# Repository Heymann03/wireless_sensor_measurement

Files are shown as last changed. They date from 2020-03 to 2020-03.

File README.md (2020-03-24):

# master research project
## Design and Realization of Wireless Measurement System for Resistive Sensors
### Objectives
1. Measuring the resistance of a sensor of any given range from 200K - 6M.
2. Displaying the data through an OLED.
3. Transmitting the acquired data to a remote station.
4. Monitoring the resistance in real-time.
5. Recording the measured data.

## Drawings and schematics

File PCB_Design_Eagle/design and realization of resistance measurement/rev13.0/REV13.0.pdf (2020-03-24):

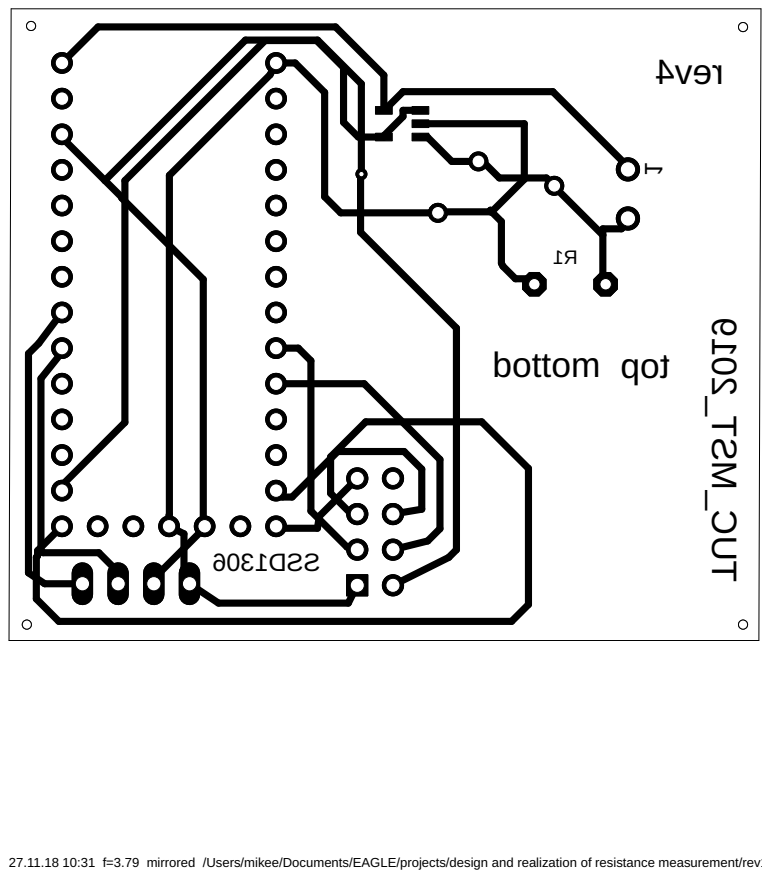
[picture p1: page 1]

27.11.18 10:31 f=3.79 mirrored /Users/mikee/Documents/EAGLE/projects/design and realization of resistance measurement/rev13.0/REV13.0.brd

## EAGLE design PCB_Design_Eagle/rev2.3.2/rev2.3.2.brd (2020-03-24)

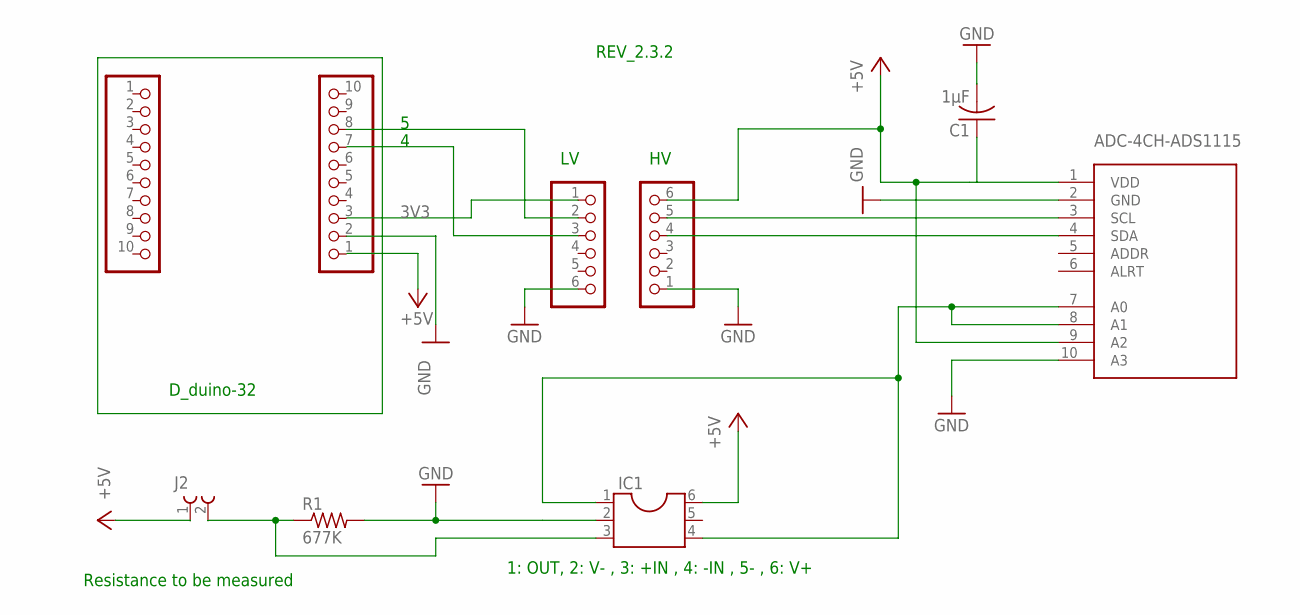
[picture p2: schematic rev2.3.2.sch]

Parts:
C1: 1µF; C025-025X050
IC1: DIL6S; SOCKET-06
J2: 691103110002
JP1, JP4: PINHD-1X6; 1X06
JP3, JP5: PINHD-1X10; 1X10
R1: 677K; 0204/5
U$1: ADC-4CH-ADS1115

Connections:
3V3: JP1.1
4: JP1.3
+5V: IC1.6, J2.1
A1: IC1.1, IC1.4, U$1.7 (A0), U$1.8 (A1)
GND: C1.2, IC1.2, JP1.6, JP4.1, JP5.2, R1.2, U$1.2 (GND), U$1.10 (A3)
unnamed: IC1.3, J2.2, R1.1
unnamed: JP1.2, JP5.8
unnamed: JP4.5, U$1.3 (SCL)
unnamed: JP4.4, U$1.4 (SDA)
VDD: C1.1, JP4.6, U$1.9 (A2)

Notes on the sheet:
Resistance to be measured
1: OUT, 2: V- , 3: +IN , 4: -IN , 5- , 6: V+
D_duino-32
REV_2.3.2

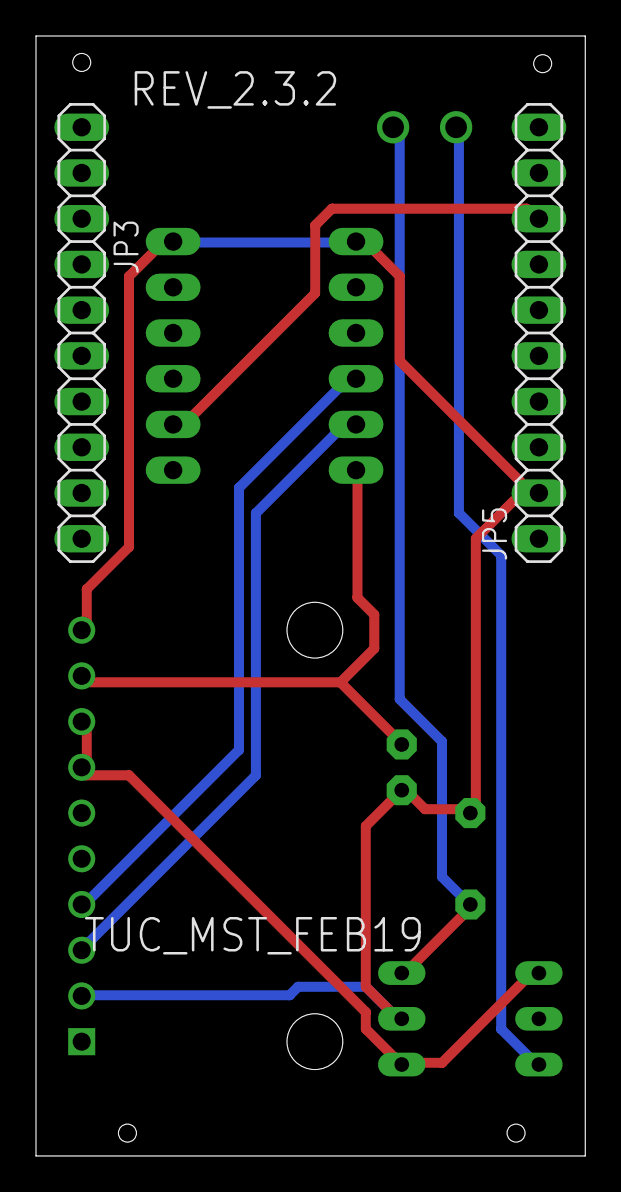
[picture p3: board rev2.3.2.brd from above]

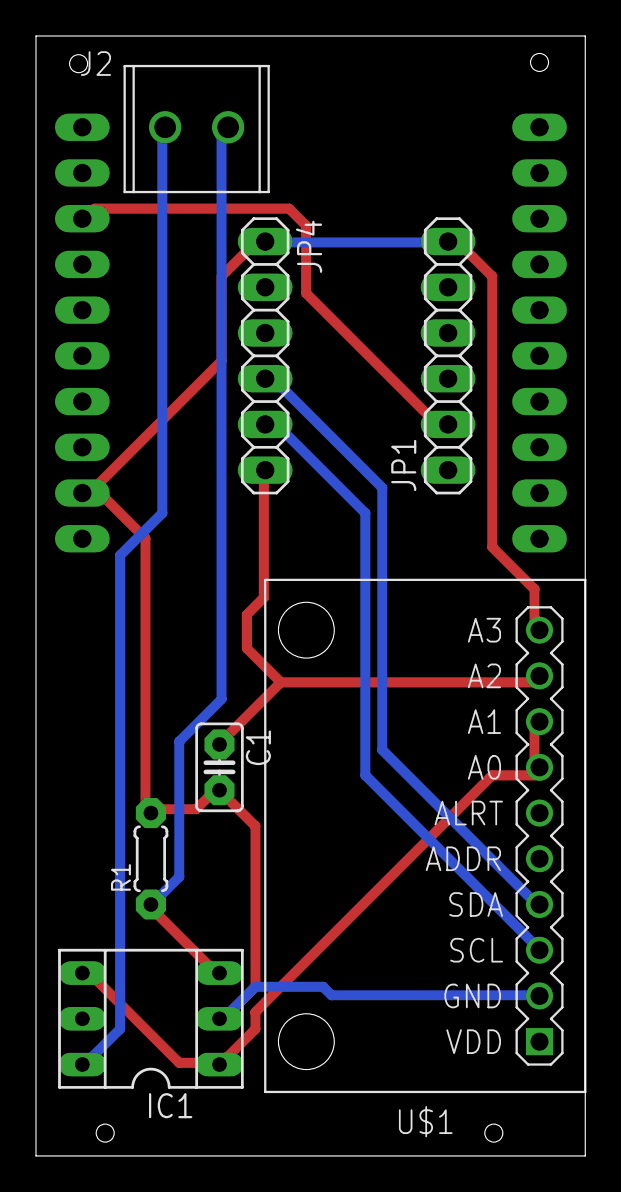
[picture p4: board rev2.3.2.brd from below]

Board: 2 copper layers, 30.5 x 62.2 mm, 9 parts (7 on the bottom side), 8 nets.

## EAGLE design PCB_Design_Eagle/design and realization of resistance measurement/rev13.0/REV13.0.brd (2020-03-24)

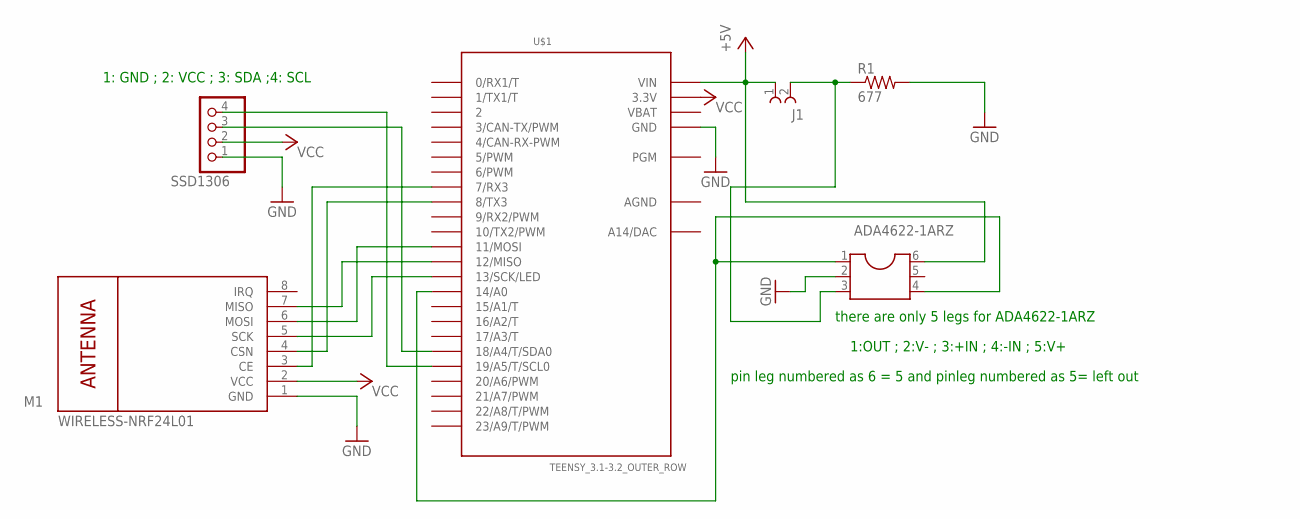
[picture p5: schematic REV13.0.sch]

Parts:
ADA4622-1ARZ: DIL6/4; DIL06-4
J1: 691214100002
M1: WIRELESS-NRF24L01
R1: 677; 0204/5
SSD1306: PINHD-1X4; 1X04
U$1: TEENSY_3.1-3.2_OUTER_ROW; TEENSY_3.0-3.2&LC_OUTER_ROW

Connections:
+5V: ADA4622-1ARZ.6, J1.1 (2), U$1.VIN
AGND: U$1.AGND
GND: ADA4622-1ARZ.2, M1.1 (GND), R1.2, SSD1306.1, U$1.GND, U$1.GND1 (GND)
unnamed: ADA4622-1ARZ.3, J1.2 (1), R1.1
unnamed: M1.5 (SCK), U$1.13 (13/SCK/LED)
unnamed: M1.6 (MOSI), U$1.11 (11/MOSI)
unnamed: M1.7 (MISO), U$1.12 (12/MISO)
unnamed: M1.4 (CSN), U$1.8 (8/TX3)
unnamed: M1.3 (CE), U$1.7 (7/RX3)
unnamed: SSD1306.4, U$1.19/A5 (19/A5/T/SCL0)
unnamed: SSD1306.3, U$1.18/A4 (18/A4/T/SDA0)
unnamed: ADA4622-1ARZ.1, ADA4622-1ARZ.4, U$1.14/A0
VBAT: U$1.VBAT
VCC: M1.2 (VCC), SSD1306.2, U$1.3.3V, U$1.3.3V1 (3.3V)

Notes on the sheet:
1: GND ; 2: VCC ; 3: SDA ;4: SCL
1:OUT ; 2:V- ; 3:+IN ; 4:-IN ; 5:V+
pin leg numbered as 6 = 5 and pinleg numbered as 5= left out
there are only 5 legs for ADA4622-1ARZ

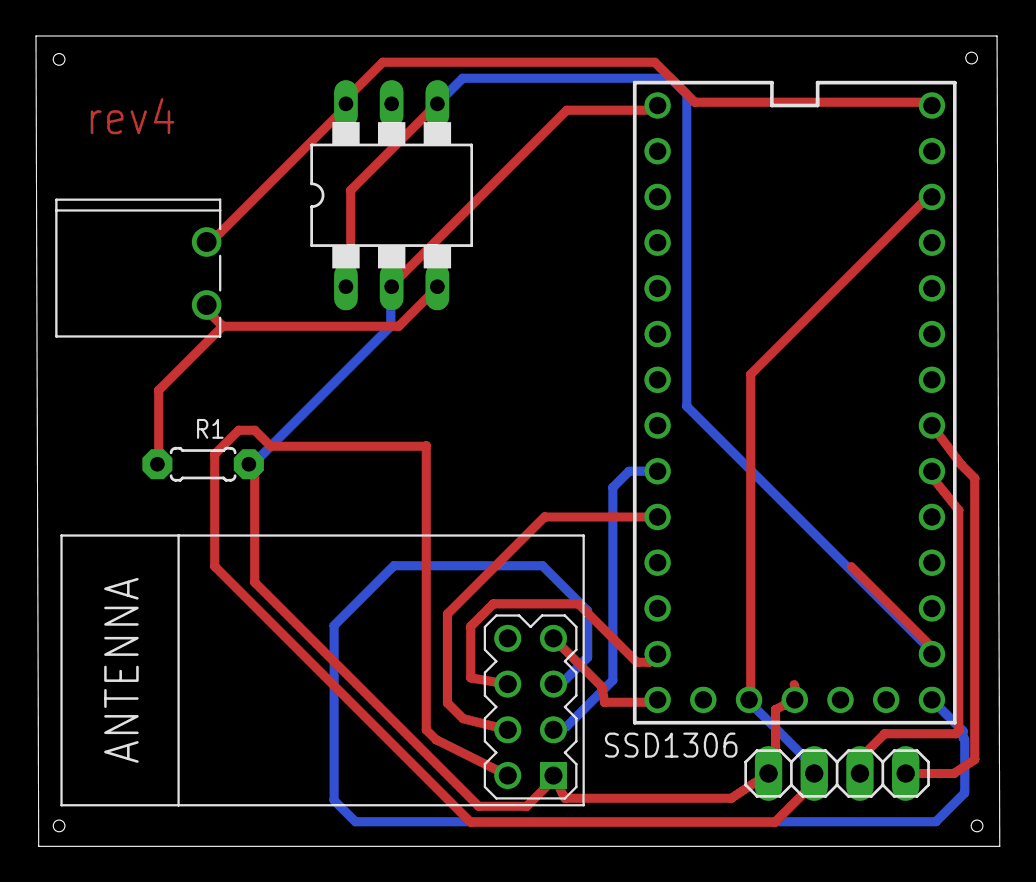
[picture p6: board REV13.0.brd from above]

Board: 2 copper layers, 53.5 x 45.0 mm, 6 parts (0 on the bottom side), 12 nets.

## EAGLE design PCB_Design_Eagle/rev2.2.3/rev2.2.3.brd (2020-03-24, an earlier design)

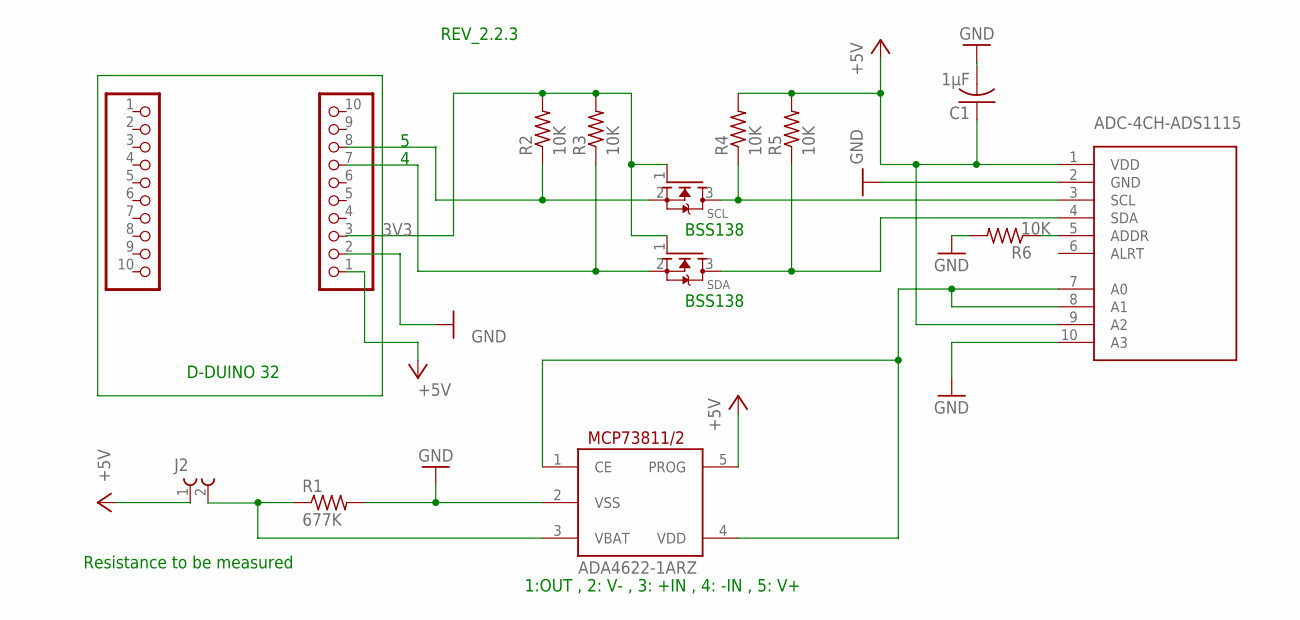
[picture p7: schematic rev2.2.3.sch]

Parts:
ADA4622-1ARZ: MCP73811/2; SOT23-5L
C1: 1µF; C1608
J2: 691103110002
JP1, JP3: PINHD-1X10; 1X10
R1: 677K; M0805
R2, R3, R4, R5, R6: 10K; M0805
SCL: MOSFET-NWAVE; SOT23-W
SDA: MOSFET-NWAVE; SOT23-W
U$1: ADC-4CH-ADS1115

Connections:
3V3: JP1.3, R2.2, R3.2, SCL.1 (G), SDA.1 (G)
4: JP1.7, R3.1, SDA.2 (S)
+5V: ADA4622-1ARZ.5 (PROG), J2.1, JP1.1
A1: ADA4622-1ARZ.1 (CE), ADA4622-1ARZ.4 (VDD), U$1.7 (A0), U$1.8 (A1)
GND: ADA4622-1ARZ.2 (VSS), C1.2, JP1.2, R1.2, R6.2, U$1.2 (GND), U$1.10 (A3)
unnamed: ADA4622-1ARZ.3 (VBAT), J2.2, R1.1
unnamed: JP1.8, R2.1, SCL.2 (S)
unnamed: R6.1, U$1.5 (ADDR)
SCL: R4.1, SCL.3 (D), U$1.3 (SCL)
SDA: R5.1, SDA.3 (D), U$1.4 (SDA)
VDD: C1.1, R4.2, R5.2, U$1.1 (VDD), U$1.9 (A2)

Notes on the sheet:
1:OUT , 2: V- , 3: +IN , 4: -IN , 5: V+
Resistance to be measured
BSS138
REV_2.2.3
D-DUINO 32

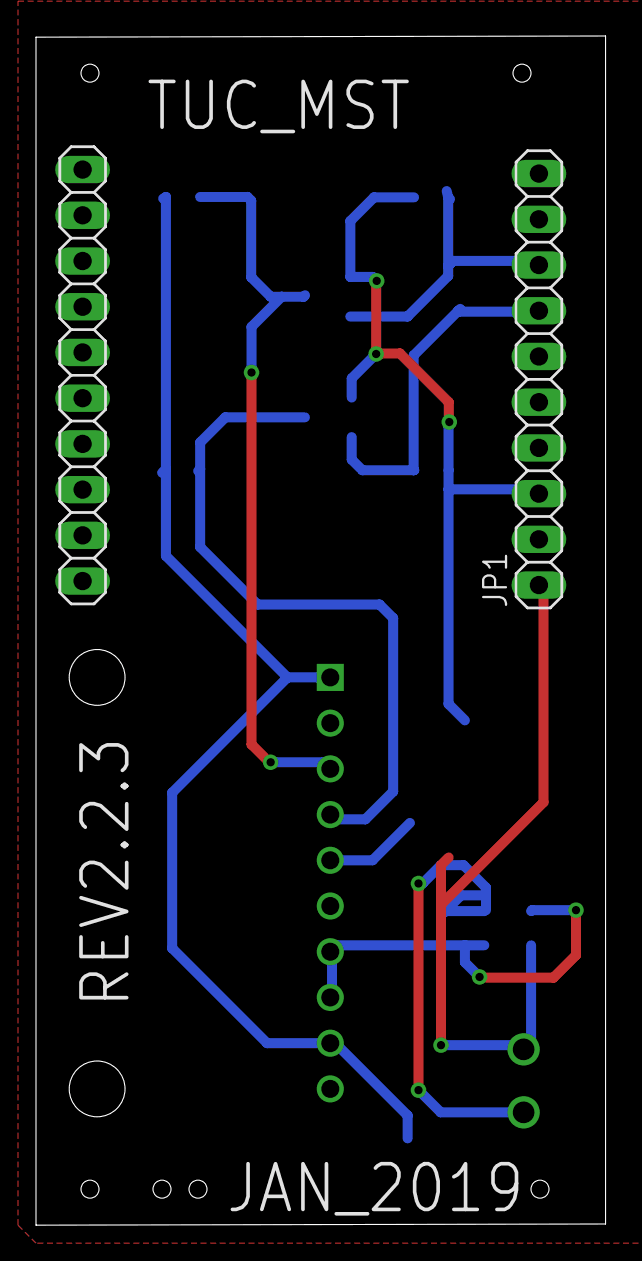
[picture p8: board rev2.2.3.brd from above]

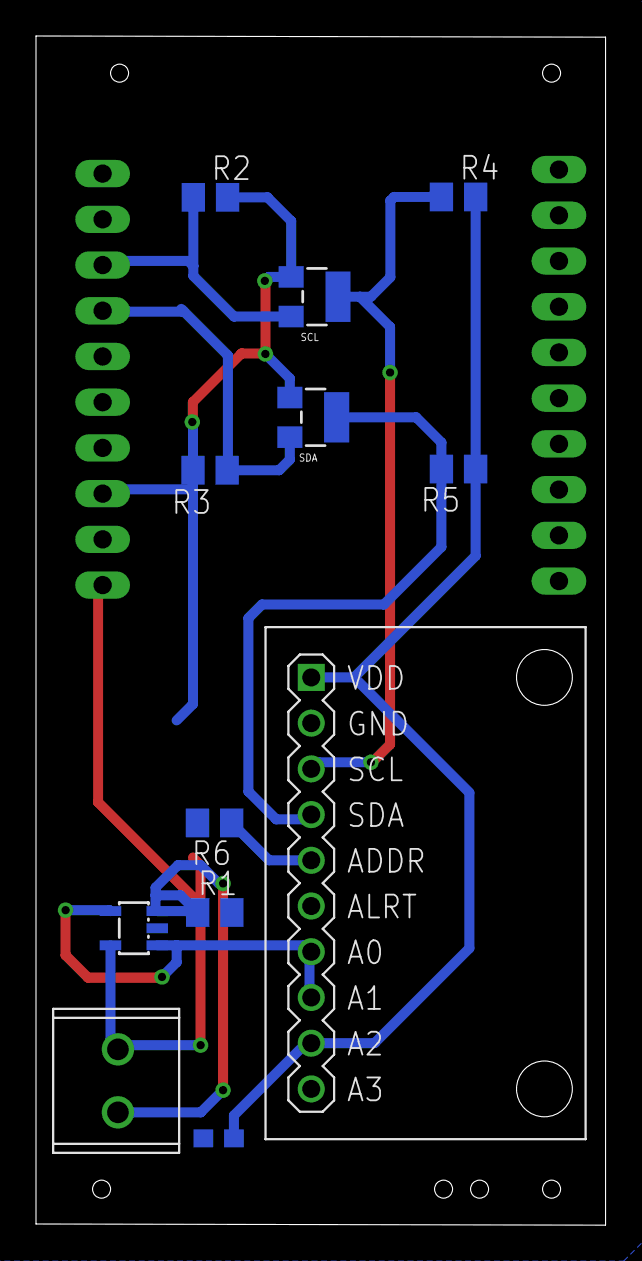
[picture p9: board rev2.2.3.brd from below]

Board: 2 copper layers, 31.6 x 66.1 mm, 14 parts (12 on the bottom side), 11 nets.

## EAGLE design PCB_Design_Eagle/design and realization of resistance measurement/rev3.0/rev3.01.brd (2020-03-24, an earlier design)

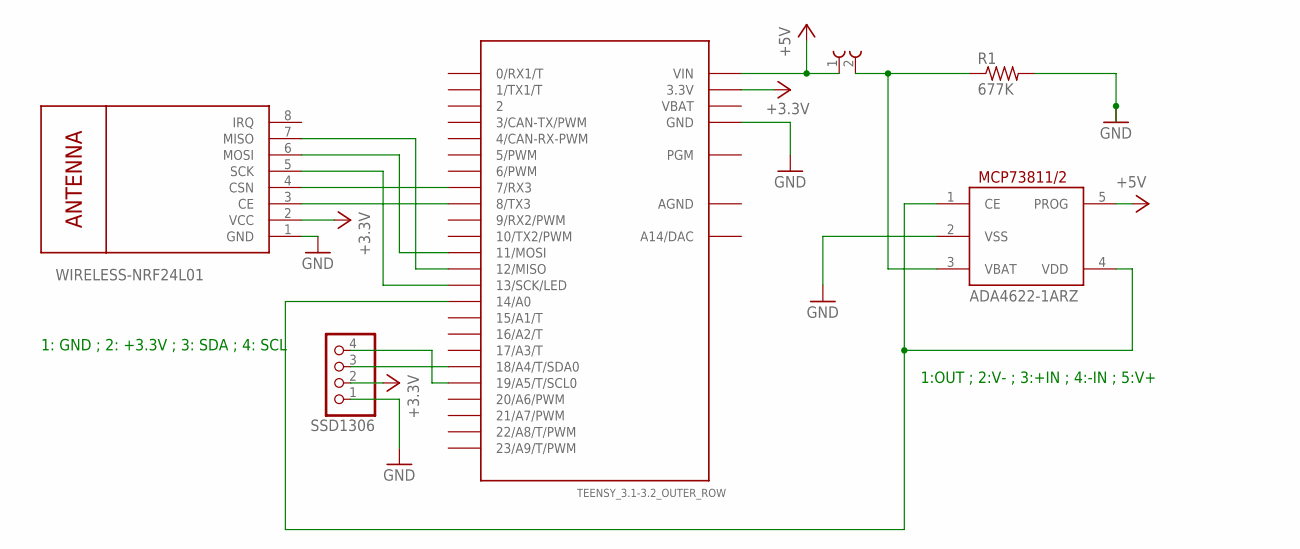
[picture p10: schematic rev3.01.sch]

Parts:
ADA4622-1ARZ: MCP73811/2; SOT23-5L
M1: WIRELESS-NRF24L01
R1: 677K; R0805W
R_MES: 691214310002
SSD1306: PINHD-1X4; 1X04
U$2: TEENSY_3.1-3.2_OUTER_ROW; TEENSY_3.0-3.2&LC_OUTER_ROW

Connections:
+5V: ADA4622-1ARZ.5 (PROG), R_MES.1, U$2.VIN
AGND: U$2.AGND
GND: ADA4622-1ARZ.2 (VSS), M1.1 (GND), R1.2, SSD1306.1, U$2.GND, U$2.GND1 (GND)
unnamed: ADA4622-1ARZ.3 (VBAT), R1.1, R_MES.2
unnamed: SSD1306.3, U$2.18/A4 (18/A4/T/SDA0)
unnamed: SSD1306.4, U$2.19/A5 (19/A5/T/SCL0)
unnamed: M1.7 (MISO), U$2.12 (12/MISO)
unnamed: ADA4622-1ARZ.1 (CE), ADA4622-1ARZ.4 (VDD), U$2.14/A0
unnamed: M1.6 (MOSI), U$2.11 (11/MOSI)
unnamed: M1.5 (SCK), U$2.13 (13/SCK/LED)
unnamed: M1.4 (CSN), U$2.7 (7/RX3)
unnamed: M1.3 (CE), U$2.8 (8/TX3)
V+: M1.2 (VCC), SSD1306.2, U$2.3.3V, U$2.3.3V1 (3.3V)
VBAT: U$2.VBAT

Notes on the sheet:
1: GND ; 2: +3.3V ; 3: SDA ; 4: SCL
1:OUT ; 2:V- ; 3:+IN ; 4:-IN ; 5:V+

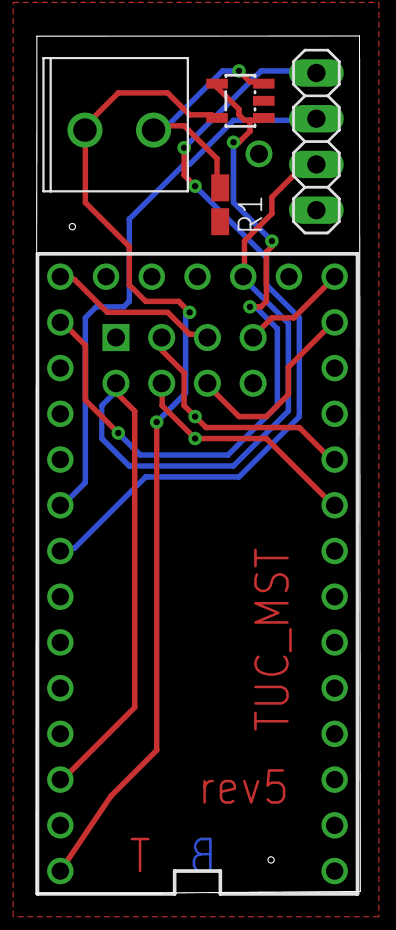
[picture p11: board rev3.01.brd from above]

Board: 2 copper layers, 18.0 x 47.7 mm, 6 parts (1 on the bottom side), 12 nets.

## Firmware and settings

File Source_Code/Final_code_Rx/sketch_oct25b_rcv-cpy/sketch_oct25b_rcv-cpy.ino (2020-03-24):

#include <SPI.h>
#include <nRF24L01.h>
#include <RF24.h>

RF24 radio(7, 8); // CE, CSN
const byte address[6] = "00001";

byte package[32];

void setup() {
  Serial.begin(9600);
  radio.begin();
  radio.setRetries(10, 15);
  radio.setDataRate(RF24_250KBPS);
  radio.openReadingPipe(0, address);
  radio.setPALevel(RF24_PA_MIN);
  radio.startListening();
  Serial.println("***Starting to receive***");
}
void loop() {
  
  char text[16] = "";
  float var;
  if (radio.available()) {
    radio.read(&text, sizeof(text));
    radio.read( package, sizeof( package ) );
    memcpy(  &var, package, sizeof( var ) );
    //decode
    
    
    Serial.println(text);
    delay(100);
    Serial.println( var );
   
//    char text[32] = "";
 //  radio.read(&text, sizeof(text));
//    int x ;
//    radio.read(&x, sizeof(x));
//    Serial.println(x);
//    
  //Serial.println(text);
  delay(1000);
  }
}

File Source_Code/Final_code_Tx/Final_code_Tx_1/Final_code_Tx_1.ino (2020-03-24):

#include <SPI.h>
#include <nRF24L01.h>
#include <RF24.h>
#include <Adafruit_SSD1306.h>
#include <Adafruit_GFX.h>
#include <gfxfont.h>
#include<Wire.h>

float Rg = 0.0f;
float Vin = 5.0f;
float Vout = 0.0f;
float Rref = 677000;
float analogInput = 0.0;      //define analog input check for kind of addressing it takes

RF24 radio(7, 8); // CE, CSN

const byte address[6] = "00001";

byte package[32];

#define OLED_RESET 4
Adafruit_SSD1306 display(OLED_RESET);

 //unsigned long Time1 = 0;
 //unsigned long Time2 = 0;
void setup() {
  // put your setup code here, to run once:
    //analogReadResolution(10);  
    Serial.begin(9600);
    radio.begin();
    radio.setRetries(10, 15);
    radio.setDataRate(RF24_250KBPS);
    radio.openWritingPipe(address);
    radio.setPALevel(RF24_PA_MIN);
    radio.stopListening();

    // setting up OLED
    
   pinMode(analogInput, INPUT);
   display.begin(SSD1306_SWITCHCAPVCC, 0X3C);//INTIALIZE WITH THE I2C ADDR 0X3C (FOR THE 128X32)
   display.clearDisplay();//clear the buffer
   display.setTextSize(2);//text display voltmeter
   display.setTextColor(WHITE);
   display.setCursor(0,0);
   display.print("W S M\n");
   display.display();
   display.setTextSize(1);
   display.setTextColor(WHITE);
   display.print("Rg = \n");
   display.display();
   display.setTextSize(1);
   display.setTextColor(WHITE);
   display.print("Vout = ");
   display.display();
   Serial.println(" Starting Measurement "); 
}

void loop() {
  // put your main code here, to run repeatedly:
  // code for calculating variable resistance using voltage follower
  float analogInput=analogRead(A1);
  float Vout = (Vin * analogInput)/4096; // 1024 for arduino uno, converting 5v into digital values
  float Rg = (Rref* ((Vin/Vout)-1));//formula for calculating variable resistance 

  
    Serial.println("***starting to send***");//print before copying and transmiting
    
    memcpy( package, &Rg,  sizeof( Rg ) );//copy data in the form of a package 
    radio.write(package, sizeof(package));// write the pacakage into the channel 

   //Time1 = millis();
   //Serial.println(Time1);
  // code for running cotinuous values on OLED
  display.setTextSize(1); //text display voltmeter
  display.setTextColor(WHITE, BLACK);
  display.setCursor(50,16);
  display.print(Rg);
  display.display();
  display.setTextSize(1);
  display.setTextColor(WHITE, BLACK);
  display.setCursor(50, 24);
  display.print(Vout);
  display.display();
  Serial.println(Vout);
  Serial.println(Rg);
  //Time2 = millis();
  //Serial.println(Time2);
  delay(1000);
}

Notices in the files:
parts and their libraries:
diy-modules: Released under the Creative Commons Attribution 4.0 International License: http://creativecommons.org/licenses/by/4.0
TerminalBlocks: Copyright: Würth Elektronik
